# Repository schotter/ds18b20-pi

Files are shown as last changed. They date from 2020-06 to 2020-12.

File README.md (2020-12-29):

<div style="font-size: 48pt; color: #e33;">DO NOT USE!</div>

Never produced and it's constructed in a stupid way.
It ignores 1-Wire's bus structure.

<hr/>

# ds18b20-pi

A simple extension board for the raspberry pi 1 model **b** with only **26** GPIO pins.
It's purpose is to make GPIO**4** easily accessible, because it's used for the [1-Wire](https://en.wikipedia.org/wiki/1-Wire) bus.
By easily I mean by using [screw terminal](https://www.reichelt.de/leiterplattenklemme-3-polig-rm-3-5-mm-dg350-3-5-3-p276225.html?&nbc=1)s.
As the [1-Wire](https://en.wikipedia.org/wiki/1-Wire) bus is a **bus**, it makes no sense to create several junctions on the pcb.
Just turn the cable into a [cable harness](https://en.wikipedia.org/wiki/Cable_harness).

That "trick" created space which is now used to switch a floor heating's automatic control electric motor.
Those motors are pretty dumb.
If powered the motor opens the valve, if not it closes the valve.
So there is no communication protocol, just a simple "on/off switch" that can be implemented by a GPIO pin, a relay, a [free-wheeling diode](https://en.wikipedia.org/wiki/Flyback_diode) and a [mosfet](https://en.wikipedia.org/wiki/MOSFET) because the relay needs 5V.
Normally I would add a pull-down resistor (10k) to every mosfet's gate, but there is not enough space.
If things get messy it should be possible to place tht resistors at the bottom side or maybe even just smd resistors between every mosfet's source (square) and gate (middle) pin.

The green leds were added to signal the relay's status and are kind of optional.
As the wires to all sensors got pretty long a [tvs-diode](https://en.wikipedia.org/wiki/Transient-voltage-suppression_diode) was added to prevent damage from esd events.
Unfortunately there is no tht version so I had to pick a smd package.

## bom

| part | description | price | manufacturer | datasheet |
|---|---|---|---|---|
| [2N 7000 DIO](https://www.reichelt.de/mosfet-n-ch-60v-0-115a-0-4w-to-92-2n-7000-dio-p219075.html) | n-channel mosfet | 0,08 € | [diotec](https://diotec.com/en/productlist.html?productfamily=FET) | [pdf](https://diotec.com/tl_files/diotec/files/pdf/datasheets/2n7000.pdf) |
| [BAT 48 STM](https://www.reichelt.de/schottkydiode-40-v-0-35-a-do-35-bat-48-stm-p219563.html) | schottky diode | 0,04 € | [st](https://www.st.com/en/diodes-and-rectifiers/bat48.html) | [pdf](https://www.st.com/resource/en/datasheet/bat48.pdf) |
| [DG350 3,5-2](https://www.reichelt.de/leiterplattenklemme-2-polig-rm-3-5-mm-dg350-3-5-2-p276224.html) | connector 2-pins | 0,19 € | [degson](http://degson.de/en/pro_detail/id/542) | [pdf](http://degson.de/en/downpdf/id/542.html) |
| [DG350 3,5-3](https://www.reichelt.de/leiterplattenklemme-3-polig-rm-3-5-mm-dg350-3-5-3-p276225.html) | connector 3-pins | 0,28 € | [degson](http://degson.de/en/pro_detail/id/542) | [pdf](http://degson.de/en/downpdf/id/542.html) |
| [HJR-4102-L 5V](https://www.reichelt.de/dil-miniaturrelais-hjr-4102-5v-1-wechsler-5a-hjr-4102-l-5v-p101950.html) | relay | 0,62 € | [tianbo](http://www.tianbo-relay.com/en/products.php?tid=10) | [pdf](http://www.tianbo-relay.com/upload/2019062414532076.pdf) |
| [K-O RD12JN152T52](https://www.reichelt.de/widerstand-kohleschicht-1-5-kohm-0411-500-mw-5-k-o-rd12jn152t52-p237423.html) | 1,5k resistor | 0,08 € | | |
| [LED 3MM 5V GN](https://www.reichelt.de/led-3-mm-bedrahtet-5-v-gruen-20-mcd-60-led-3mm-5v-gn-p54093.html) | green led with embedded resistor | 0,31 € | [kingbright](https://www.kingbright.com/content/listitem/psearch/259) | [pdf](https://cdn-reichelt.de/documents/datenblatt/A500/L-934GD-5V.pdf) |
| [PESD3V3S2UT](https://www.reichelt.de/doppe-esd-schutzdiode-3-3-vrwm-20-vcl-30kv-sot-23-pesd3v3s2ut-p271905.html) | TVS-diode | 0,12 € | [nxp](https://www.nexperia.com/products/esd-protection-tvs-filtering-and-signal-conditioning/automotive-esd-protection-and-tvs/automotive-esd-protection/PESD3V3S2UT.html) | [pdf](https://assets.nexperia.com/documents/data-sheet/PESDXS2UT_SERIES.pdf) |

## schematic

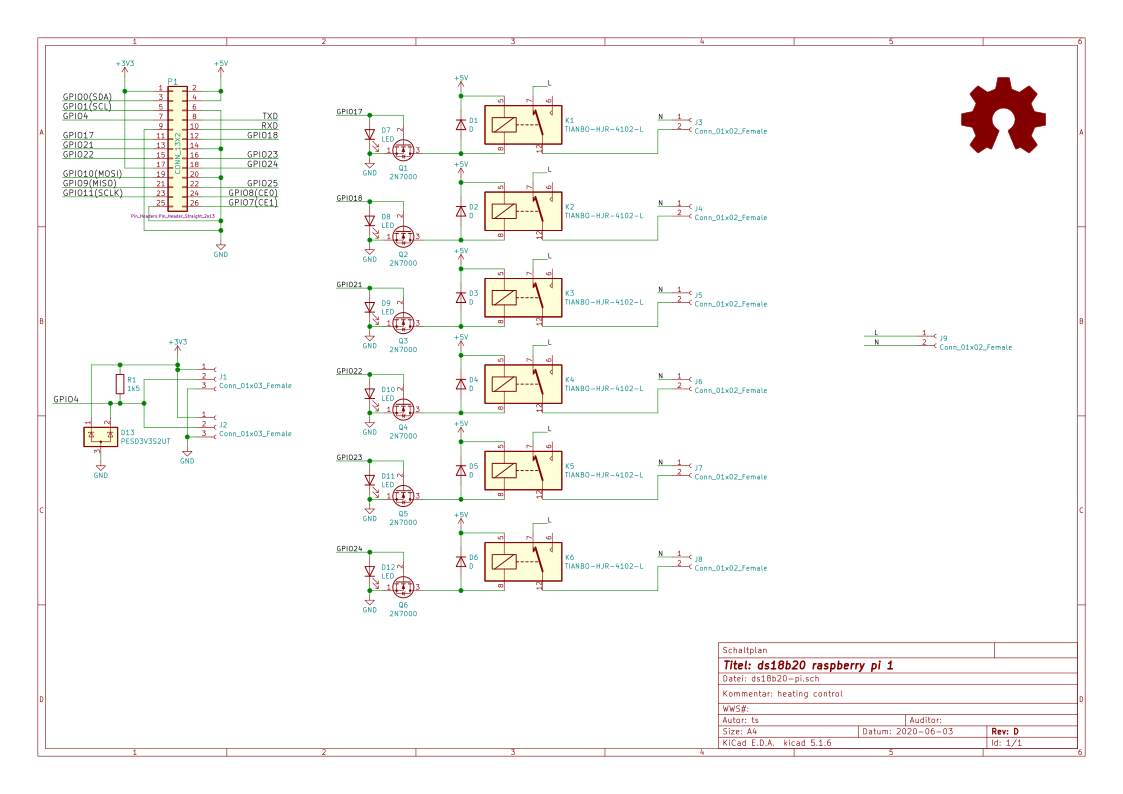
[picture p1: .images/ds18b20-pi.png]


## board

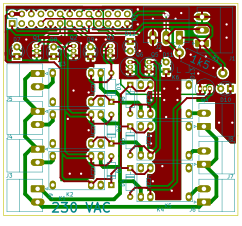
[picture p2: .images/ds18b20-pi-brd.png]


## rendering 

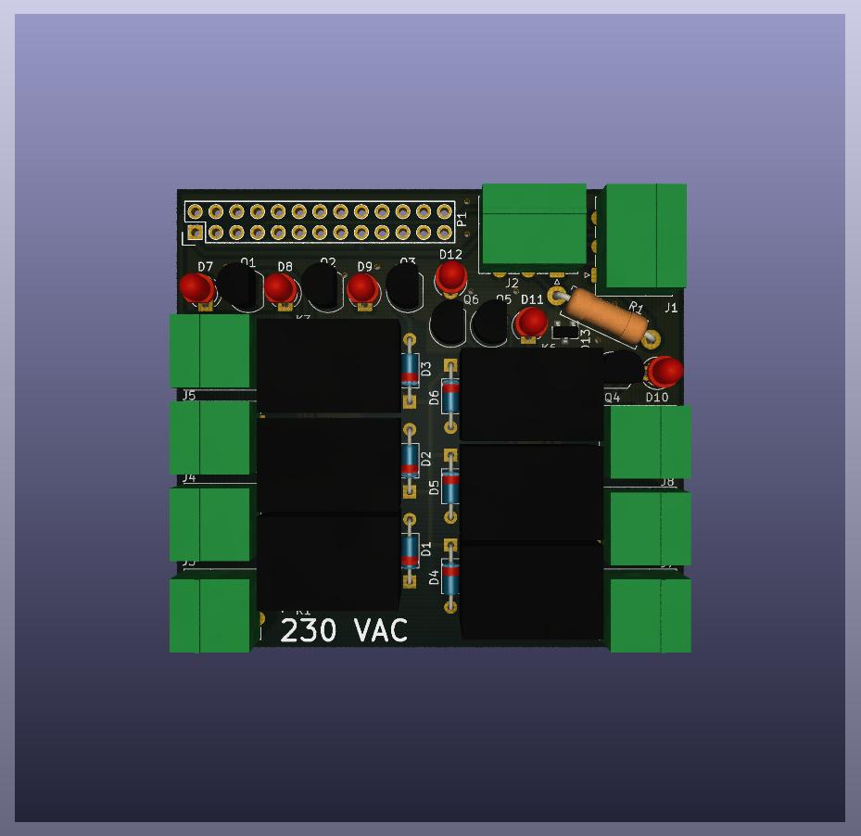
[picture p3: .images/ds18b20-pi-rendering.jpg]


Raspberry Pi 1 GPIO extension board for the 1-wire bus

## note

* `pcb_new`: `File -> Export -> SVG`, *all layers in a single file*, *print board edges*, *color*
* `eeschema`: `File -> Plot`, *SVG*, *Page Size: A4*, *Output mode: color*, *Plot border and title block*

```
$ convert -background white schematic_export.svg schematic_export.png
$ convert -background none board_export.svg board_export.png
```

`convert` is part of [ImageMagick](https://imagemagick.org/index.php).

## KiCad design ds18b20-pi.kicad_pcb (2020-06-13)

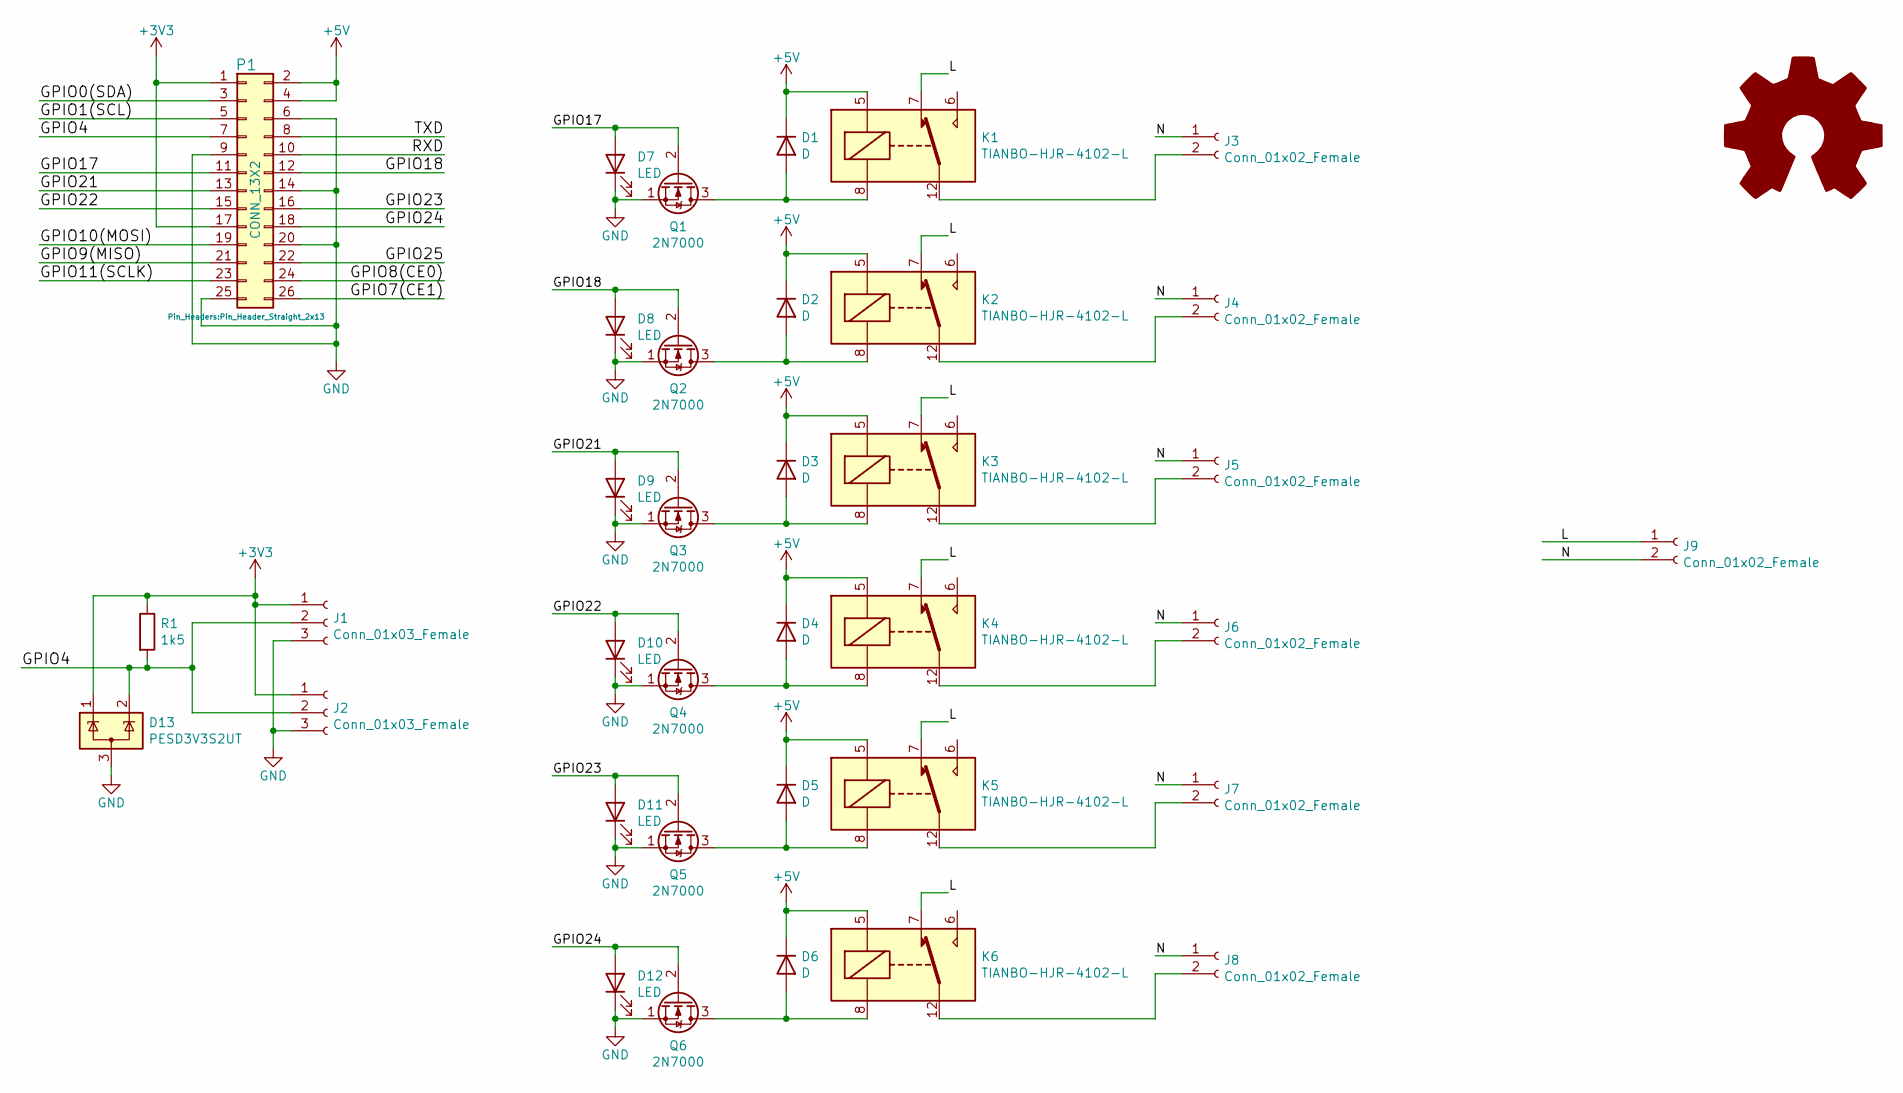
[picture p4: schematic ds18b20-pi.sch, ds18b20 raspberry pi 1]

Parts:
D1, D2, D3, D4, D5, D6: D; D_DO-35_SOD27_P7.62mm_Horizontal
D7, D8, D9, D10, D11, D12: LED; LED_D3.0mm
D13: PESD3V3S2UT; SOT-23
J1, J2: Conn_01x03_Female; PhoenixContact_MC_1,5_3-G-3.5_1x03_P3.50mm_Horizontal
J3, J4, J5, J6, J7, J8, J9: Conn_01x02_Female; PhoenixContact_MC_1,5_2-G-3.5_1x02_P3.50mm_Horizontal
K1, K2, K3, K4, K5, K6: TIANBO-HJR-4102-L; Relay_SPDT_HJR-4102
P1: CONN_13X2; Pin_Header_Straight_2x13
Q1, Q2, Q3, Q4, Q5, Q6: 2N7000; TO-92_Inline
R1: 1k5; R_Axial_DIN0411_L9.9mm_D3.6mm_P12.70mm_Horizontal

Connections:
+3V3: D13.1 (K), J1.1, J2.1, P1.1, P1.17, R1.1
+5V: D1.1 (K), D2.1 (K), D3.1 (K), D4.1 (K), D5.1 (K), D6.1 (K), K1.5, K2.5, K3.5, K4.5, K5.5, K6.5, P1.2, P1.4
/GPIO0(SDA): P1.3
/GPIO1(SCL): P1.5
/GPIO4: D13.2 (K), J1.2, J2.2, P1.7, R1.2
/GPIO7(CE1): P1.26
/GPIO8(CE0): P1.24
/GPIO9(MISO): P1.21
/GPIO10(MOSI): P1.19
/GPIO11(SCLK): P1.23
/GPIO17: D7.2 (A), P1.11, Q1.2 (G)
/GPIO18: D8.2 (A), P1.12, Q2.2 (G)
/GPIO21: D9.2 (A), P1.13, Q3.2 (G)
/GPIO22: D10.2 (A), P1.15, Q4.2 (G)
/GPIO23: D11.2 (A), P1.16, Q5.2 (G)
/GPIO24: D12.2 (A), P1.18, Q6.2 (G)
/GPIO25: P1.22
/L: J9.1, K1.7, K2.7, K3.7, K4.7, K5.7, K6.7
/N: J3.1, J4.1, J5.1, J6.1, J7.1, J8.1, J9.2
/RXD: P1.10
/TXD: P1.8
GND: D7.1 (K), D8.1 (K), D9.1 (K), D10.1 (K), D11.1 (K), D12.1 (K), D13.3 (A), J1.3, J2.3, P1.6, P1.9, P1.14, P1.20, P1.25, Q1.1 (S), Q2.1 (S), Q3.1 (S), Q4.1 (S), Q5.1 (S), Q6.1 (S)
unnamed: D1.2 (A), K1.8, Q1.3 (D)
unnamed: D2.2 (A), K2.8, Q2.3 (D)
unnamed: D3.2 (A), K3.8, Q3.3 (D)
unnamed: D4.2 (A), K4.8, Q4.3 (D)
unnamed: D5.2 (A), K5.8, Q5.3 (D)
unnamed: D6.2 (A), K6.8, Q6.3 (D)
unnamed: J3.2, K1.12
unnamed: J4.2, K2.12
unnamed: J5.2, K3.12
unnamed: J6.2, K4.12
unnamed: J7.2, K5.12
unnamed: J8.2, K6.12

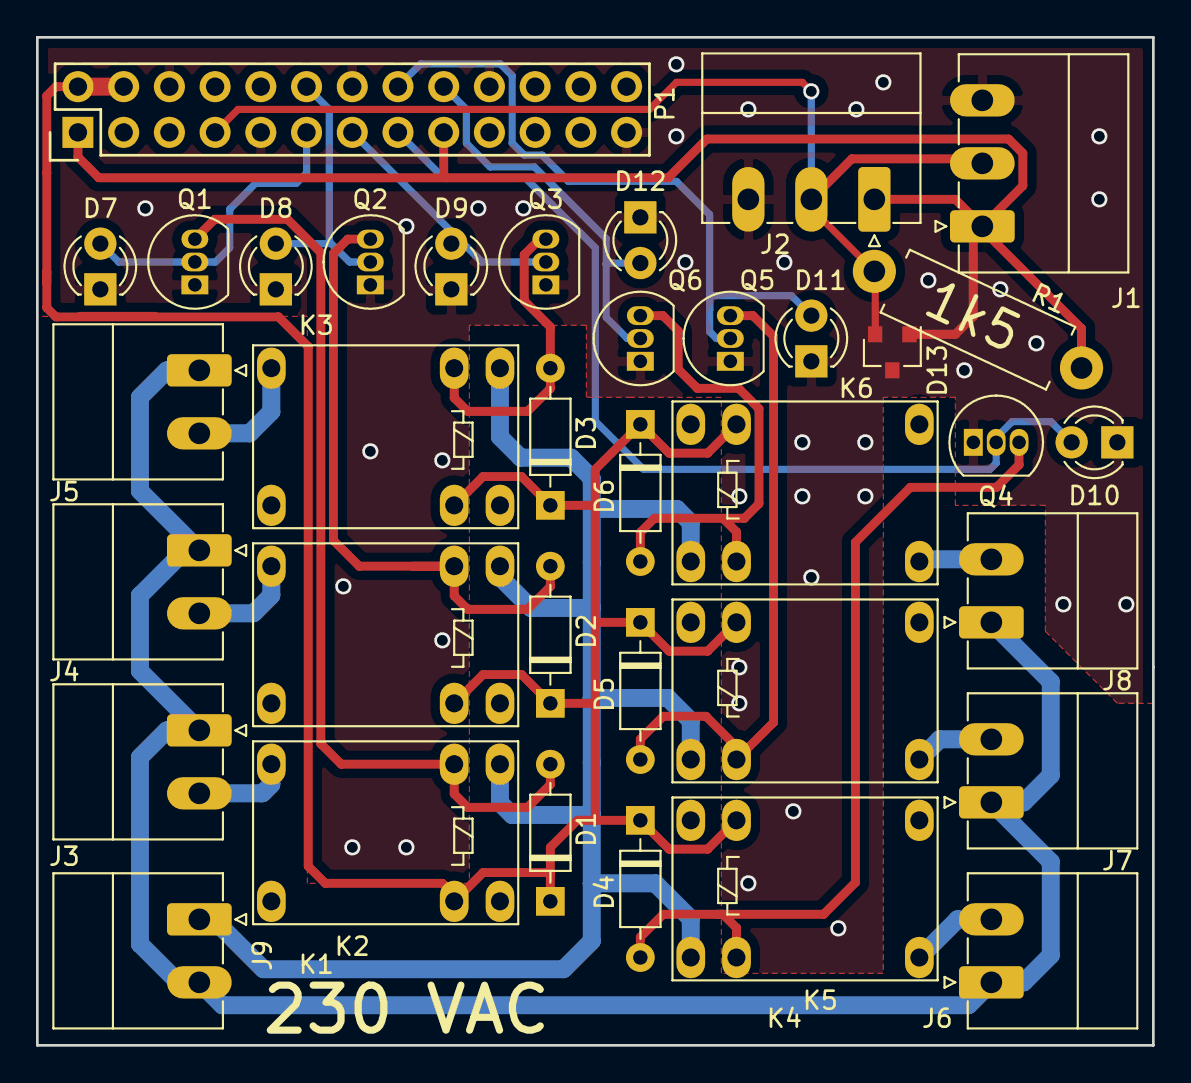
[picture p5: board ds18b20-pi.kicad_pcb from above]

Board: 2 copper layers, 62.0 x 56.0 mm, 36 parts (0 on the bottom side), 24 nets.

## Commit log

2020-05-29 GPIO4 accessible, 10 slaves combinable
    * DG350 3,5-3: https://www.reichelt.de/leiterplattenklemme-3-polig-rm-3-5-mm-dg350-3-5-3-p276225.html
    The connector used for the rendering is the wrong one, but it has the
    pitch. So it's acceptable.
    [ds18b20-pi.kicad_pcb, ds18b20-pi.sch]
2020-05-30 Less GPIO4 more relays for motors
    [ds18b20-pi.kicad_pcb, ds18b20-pi.sch]
2020-05-30 More Vias and more GND
    [ds18b20-pi.kicad_pcb]
2020-05-30 bom: relay
2020-05-30 bom: 1,5k resistor
2020-05-31 bom: manufacturer + datasheet
2020-06-03 Indicator led for each relay
    There are leds that already have a series resistor included to limit the
    current. Those leds are necessary for this board, because there is not
    enough space for addition resistors.
    [ds18b20-pi.kicad_pcb, ds18b20-pi.sch]
2020-06-03 oshw logo
    [ds18b20-pi.kicad_pcb]
2020-06-13 tvs diode
    The sensors are connected through long wires, which make it very likely
    for radiation to couple into them and disturb the communication.
    Therefore a tvs diode was added. Unfortunately for a breakdown voltage
    of 3,3V there are only smd packages available.
    [ds18b20-pi.kicad_pcb, ds18b20-pi.sch]
